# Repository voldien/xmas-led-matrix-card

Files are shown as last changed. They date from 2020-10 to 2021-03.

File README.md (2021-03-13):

# Christmas LED Board

Remark that the schematic and PCB layout and the software driver are still work in progress and still have bugs both in the hardware and software.

DQcKnOpVwAAkGqP2

# Motivation

## Installation

### Unix
The driver for *UNIX* system can be installed as followed:
```
make 
make install
```

# License
The source code for this project is licensed under the GPL+3 License - see the [LICENSE](LICENSE) file for details.
The hardware design for this project is under the OSHW License - See [](LICENSE) for more detials.

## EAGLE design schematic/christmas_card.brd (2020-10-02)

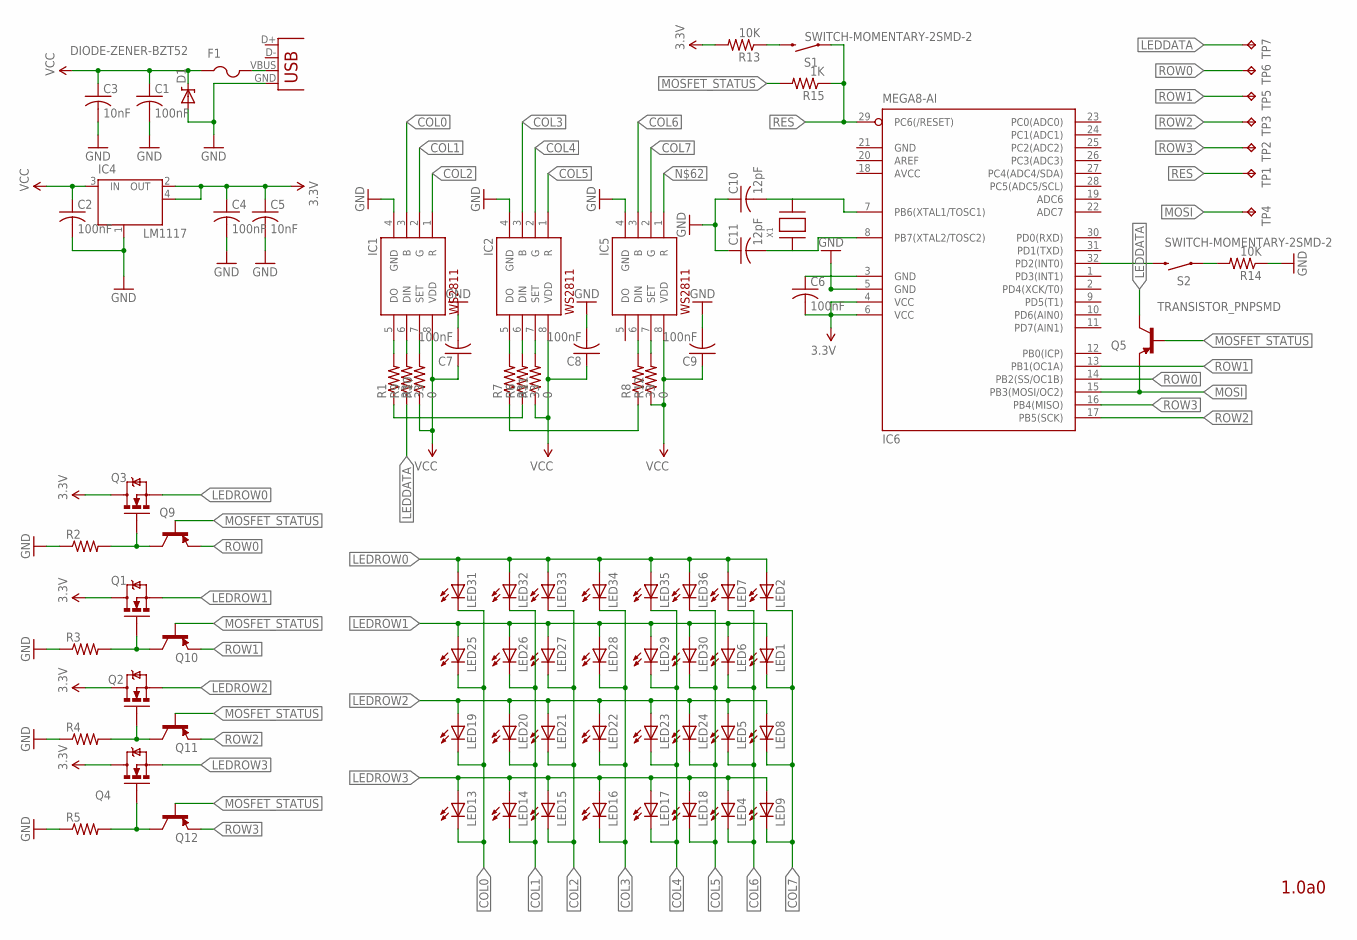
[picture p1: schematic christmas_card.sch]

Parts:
C1, C2, C4, C6, C7, C8, C9: 100nF; C0603
C3, C5: 10nF; C0603
C10, C11: 12pF; C0603
D1: DIODE-ZENER-BZT52; SOD-323
F1: PTCFUSE-1206; R1206
IC1, IC2, IC5: WS2811-SOP8; SO08-SKINNYPADS
IC4: LM1117; SOT223
IC6: MEGA8-AI; TQFP32-08
LED1, LED2, LED4, LED5, LED6, LED7, LED8, LED9, LED13, LED14, LED15, LED16, LED17, LED18, LED19, LED20, LED21, LED22, LED23, LED24, LED25, LED26, LED27, LED28, LED29, LED30, LED31, LED32, LED33, LED34, LED35, LED36: LED1206; LED-1206
Q1, Q2, Q3, Q4: MOSFET-NCHANNELSMD; SOT23-3
Q5, Q9, Q10, Q11, Q12: TRANSISTOR_PNPSMD; SOT23-3
R1, R6, R7, R8, R9: 33; R0603
R2, R3, R4, R5: R-US_R0603; R0603
R10, R11, R12: 0; R0603
R13, R14: 10K; R0603
R15: 1K; R0603
S1, S2: SWITCH-MOMENTARY-2SMD-2; TACTILE_SWITCH_SMD-2
TP1, TP2, TP3, TP4, TP5, TP6, TP7: TPB1,27; B1,27
X1: XTALNX5032; NX5032
X2: USB-MICROB

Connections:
3.3V: C4.1, C5.1, C6.2, IC4.2 (OUT), IC4.4 (OUT), IC6.4 (VCC), IC6.6 (VCC), Q1.3 (D), Q2.3 (D), Q3.3 (D), Q4.3 (D), R13.2
AVCC: IC6.18 (AVCC)
COL0: IC1.3 (B), LED13.C, LED19.C, LED25.C, LED31.C
COL1: IC1.2 (G), LED14.C, LED20.C, LED26.C, LED32.C
COL2: IC1.1 (R), LED15.C, LED21.C, LED27.C, LED33.C
COL3: IC2.3 (B), LED16.C, LED22.C, LED28.C, LED34.C
COL4: IC2.2 (G), LED17.C, LED23.C, LED29.C, LED35.C
COL5: IC2.1 (R), LED18.C, LED24.C, LED30.C, LED36.C
COL6: IC5.3 (B), LED4.C, LED5.C, LED6.C, LED7.C
COL7: IC5.2 (G), LED1.C, LED2.C, LED8.C, LED9.C
GND: C1.2, C2.2, C3.2, C4.2, C5.2, C6.1, C7.2, C8.2, C9.2, C10.1, C11.1, D1.2 (A), IC1.4 (GND), IC2.4 (GND), IC4.1 (GND/ADJ), IC5.4 (GND), IC6.3 (GND), IC6.5 (GND), IC6.21 (GND), R2.1, R3.1, R4.1, R5.1, R14.1, X2.GND
LEDDATA: Q5.3 (C), R9.1, TP7.TP
LEDROW0: LED2.A, LED7.A, LED31.A, LED32.A, LED33.A, LED34.A, LED35.A, LED36.A, Q3.2 (S)
LEDROW1: LED1.A, LED6.A, LED25.A, LED26.A, LED27.A, LED28.A, LED29.A, LED30.A, Q1.2 (S)
LEDROW2: LED5.A, LED8.A, LED19.A, LED20.A, LED21.A, LED22.A, LED23.A, LED24.A, Q2.2 (S)
LEDROW3: LED4.A, LED9.A, LED13.A, LED14.A, LED15.A, LED16.A, LED17.A, LED18.A, Q4.2 (S)
MOSFET_STATUS: Q5.1 (B), Q9.1 (B), Q10.1 (B), Q11.1 (B), Q12.1 (B), R15.2
MOSI: IC6.15 (PB3(MOSI/OC2)), Q5.2 (E), TP4.TP
unnamed: R1.1, R6.1
unnamed: IC1.5 (DO), R1.2
unnamed: IC2.6 (DIN), R6.2
unnamed: IC2.5 (DO), R7.2
unnamed: R7.1, R8.1
unnamed: IC5.6 (DIN), R8.2
unnamed: IC1.6 (DIN), R9.2
unnamed: IC5.7 (SET), R12.2
unnamed: R13.1, S1.1 (2)
unnamed: C10.2, IC6.7 (PB6(XTAL1/TOSC1)), X1.P$2
unnamed: IC6.32 (PD2(INT0)), S2.1 (2)
unnamed: R14.2, S2.2 (1)
unnamed: Q3.1 (G), Q9.3 (C), R2.2
unnamed: C11.2, IC6.8 (PB7(XTAL2/TOSC2)), X1.P$1
unnamed: IC2.7 (SET), R11.2
unnamed: IC1.7 (SET), R10.2
unnamed: F1.2, X2.VBUS
RES: IC6.29 (PC6(/RESET)), R15.1, S1.2 (1), TP1.TP
ROW0: IC6.14 (PB2(SS/OC1B)), Q9.2 (E), TP6.TP
ROW1: IC6.13 (PB1(OC1A)), Q1.1 (G), Q10.2 (E), Q10.3 (C), R3.2, TP5.TP
ROW2: IC6.17 (PB5(SCK)), Q2.1 (G), Q11.2 (E), Q11.3 (C), R4.2, TP3.TP
ROW3: IC6.16 (PB4(MISO)), Q4.1 (G), Q12.2 (E), Q12.3 (C), R5.2, TP2.TP
VCC: C1.1, C2.1, C3.1, C7.1, C8.1, C9.1, D1.1 (C), F1.1, IC1.8 (VDD), IC2.8 (VDD), IC4.3 (IN), IC5.8 (VDD), R10.1, R11.1, R12.1

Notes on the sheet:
1.0a0

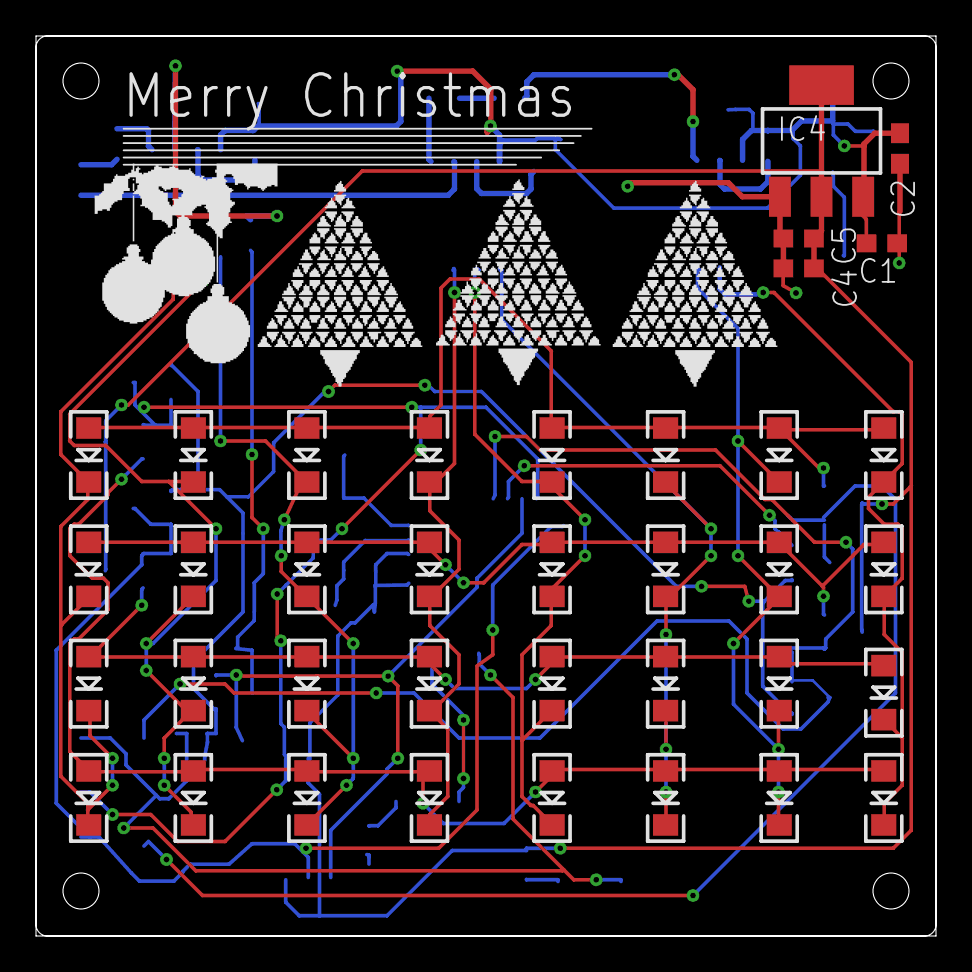
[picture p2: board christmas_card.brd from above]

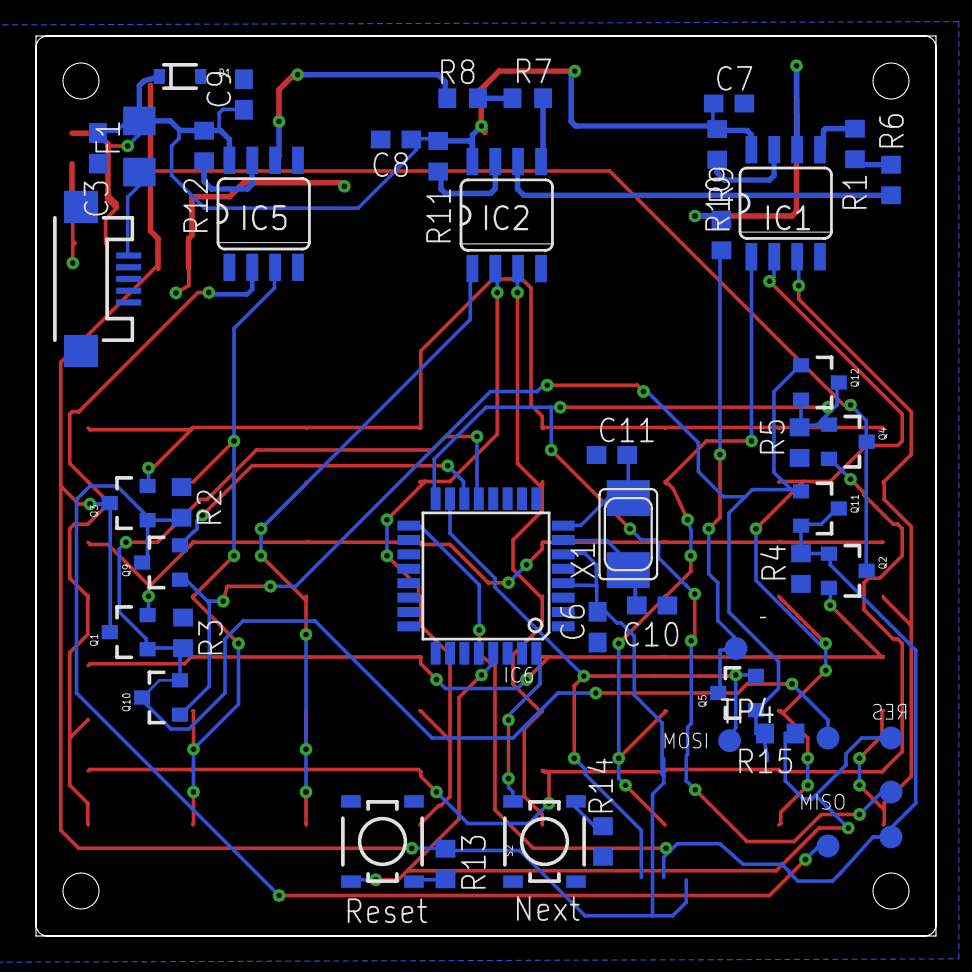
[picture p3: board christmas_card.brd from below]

Board: 2 copper layers, 50.0 x 50.0 mm, 85 parts (48 on the bottom side), 40 nets.

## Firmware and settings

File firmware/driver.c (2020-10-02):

#include"christmascard.h"
#include"animation.h"
#include<avr/boot.h>
#include<avr/interrupt.h>
#include<avr/power.h>
#include<avr/io.h>
#include<avr/common.h>
#include<avr/builtins.h>
#include<avr/wdt.h>
#include<avr/sleep.h>
#include<util/delay.h>
#include<assert.h>
#include"ws2811_8.h"

ISR(INT0_vect) {
	cc_reset_for_next_animation();
}

void cc_init_nextanibutton(void){
	/*	Output and enable pin for next button.	*/
	PORTD |= BUTTON_NEXT;
	DDRD |= BUTTON_NEXT;

	/*	Enable interrupt.	*/
	/*	External interrupt invoked on volt drop.	*/
	MCUCR |= (1 << ISC00) | ( 1 << ISC01);
	GICR |= (1 << INT0);
}

void cc_init_ledcontrollers(void){

	/*	Output and enable pin for ws2811.	*/
	DDRB |= WS2811_IN;

	/*	Output rows.	*/
	ROWDPORT |= ROWALL;
}

void cc_init_time2ovf(void){
	/*
	TIMSK |= ( 1 << TOIE2);
	*/
	/*	Enable time overflow and interrupt.	*/
	/*
	ASSR = (1<<AS2);
	TIMSK = (1 << TOIE2);
	TCCR2 |= (1 << CS02);
	TIFR = (1 << TOV2);
	*/

}

void cc_set_row(const uint8_t r){

	/*	Set all rows to sink.	 */
	ROWPORT &= ~ROWALL;
	ROWDPORT |= ROWALL;

	/*	Set specified row to source mode.	*/
	if(r == 0){
		ROWPORT |= ROW0;
	}
	else if(r == 1){
		ROWPORT |= ROW1;
	}
	else if(r == 2){
		ROWPORT |= ROW2;
	}
	else if (r == 3){
		ROWPORT |= ROW3;
	}
}

void cc_set_col(const uint8_t d[9]){

	cli();
	ws2811_send(d, 3, WS2811_PIN);
	sei();
}

void cc_display_next_keyframe(void){
	uint8_t i, j;

	/*	*/
	for(j = 0; j < NUMROWS; j++){
		uint8_t buf[9];

		/*	Fetch row data.	*/
		for (i = 0; i < NUMCOL; i++) {
			buf[i] = cc_get_curr_animation_keyframe(j, i);
		}

		cc_set_col(buf);
		cc_set_row(j);

		//_delay_ms(1000);
		_delay_us(30);
	}
	//_delay_us(15);
}

void cc_select_led_controller(void) {
	DDRC |= (1 << PC6);
	PORTC |= (1 << PC6);
}

void init(void) {
	/*	Disable interrupt intill
	 *	the initialization part is done.*/
	cli();

#if F_CPU == 16000000 && 0
	clock_prescale_set(clock_div_2);
#endif

	/*	Enable all required components of the MCU.	*/
	cc_init_ledcontrollers();

	/*	*/
	cc_init_nextanibutton();

	/*	*/
	cc_init_animation();

	/*	*/
	cc_init_time2ovf();

	/*	*/
	cc_select_led_controller();

	sleep_enable();
	set_sleep_mode(SLEEP_MODE_IDLE);

	sei();
}

int main(void) {

	init();

	/*	main logic.	*/
	while (1) {
		uint8_t i = 0;
		const uint8_t it = 144; /*	How long the display will be lit.	*/

		/*	Refresh the LED n number of times.	*/
		for (i = 0; i < it; i++) {
			cc_display_next_keyframe();

		}

		/*	Change to next animation.*/
		if (cc_next_animation_ready()) {
			cc_reset_for_next_animation();
			continue;
		}

		/*	Next frame.	*/
		cc_next_frame();
	}

	return 0;
}

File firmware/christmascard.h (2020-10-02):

/**
	Simple Christmascard MCU driver.
	Copyright (C) 2017  Valdemar Lindberg

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
*/
#ifndef _CHRISTMAS_CARD_H_
#define _CHRISTMAS_CARD_H_ 1
#include<stdio.h>

/**
 *	constant global attributes.
 */
#define ROW0 (1 << PB2)
#define ROW1 (1 << PB1)
#define ROW2 (1 << PB5)
#define ROW3 (1 << PB4)
#define ROWALL (ROW0 | ROW1 | ROW2 | ROW3)
#define ROWPORT PORTB
#define ROWDPORT DDRB
#define NUMROWS 4
#define NUMCOL 8

/**
 *
 */
#define BUTTON_NEXT (1 << PD2)
#define WS2811_PIN	PB3
#define WS2811_IN (1 << WS2811_PIN)

/**
 *	Animation and LED.
 */
extern void cc_set_row(const uint8_t r);		/*	Set current enabled row.	*/
extern void cc_set_col(const uint8_t* d);		/*	Update LED driver with 8 bytes for current row.	*/
extern void cc_display_next_keyframe(void);		/*	Display next current key frame.	*/
extern void cc_select_led_controller(void);		/*	Select LED controller.	*/
extern void cc_select_flash_controller(void);	/*	Select Flash Controller.	*/

/**
 *	Button, controller and timers.
 */
extern void cc_init_nextanibutton(void);	/*	Initialize next animation button interrupt.	*/
extern void cc_init_ledcontrollers(void);	/*	Initialize LED controller.	*/
extern void cc_init_time2ovf(void);			/*	Enable timer overflow interrupt for update.	*/

#endif

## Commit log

2020-10-02 Added init source files.
    [christmas_card.brd, christmas_card.sch]
2021-03-13 Update README.md
    Added image of the work in progress board.

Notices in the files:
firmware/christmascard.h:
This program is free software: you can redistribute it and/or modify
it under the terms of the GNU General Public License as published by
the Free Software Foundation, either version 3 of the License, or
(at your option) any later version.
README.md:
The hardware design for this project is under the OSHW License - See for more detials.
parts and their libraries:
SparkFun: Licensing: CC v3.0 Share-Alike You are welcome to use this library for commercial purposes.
